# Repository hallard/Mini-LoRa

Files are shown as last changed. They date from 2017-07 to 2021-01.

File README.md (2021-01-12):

Mini Lora Node, Arduino Mini LoraWAN sensor
===========================================

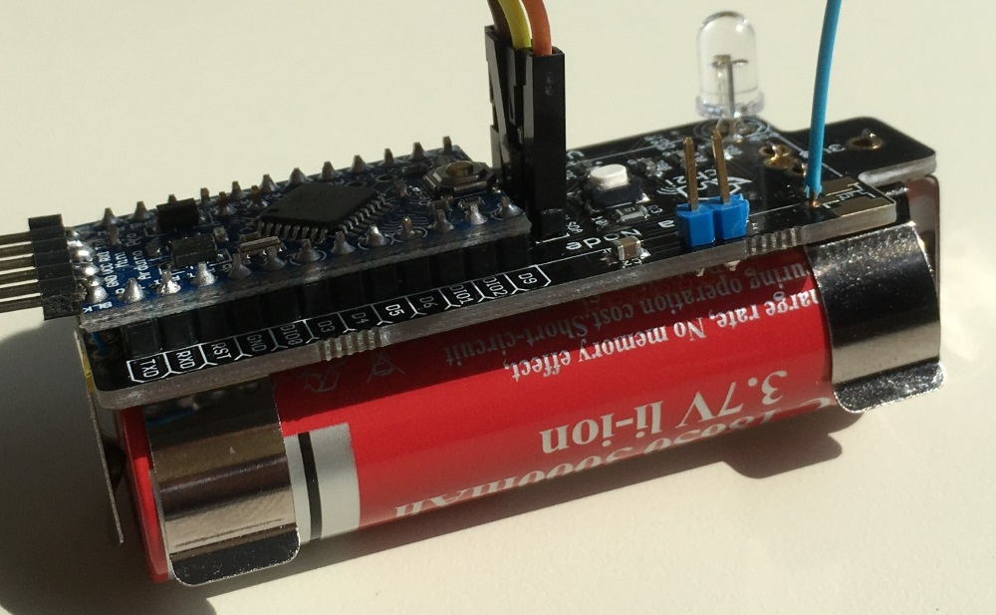
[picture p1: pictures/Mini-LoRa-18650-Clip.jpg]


At the begining this PCB has been created to help wiring between Arduino Mini and RFM95 Lora module and to be able to put the whole thing powered by various Batteries type (AA, 18650, A, ...).

Then I decided to add some funky stuff like:

**new in V1.2**

- Footprint for Ultra Low Power controller TPL5110
- R9 1206 or PTH Footprint to easily change resistor and thus delay between wake
- renamed silk pin to function instead of arduino name
- Optional Tactile Switch to wake from TPL5110

**all version**

- Easy to build and solder, 0805 or PTH components
- I2C connector (or grove) to be able to add internal/external sensors such as BME280, SI7021 or HTU21D
- Footprint for Lora RFM95
- Footprint for a Microchip 24AA02E64T EUID 
- RBG Led
- Optional Tactile Switch
- Various Battery Connector and type AA/A/18650/CR123
- Two A4/A5 pins position so you can use different Mini Clone (see BOM)

**On version 1.1, I2C A4/A5 (the ones bottom right) are not connected**, thanks to tkerby who detected this point on [issue #1](https://github.com/hallard/Mini-LoRa/issues/1).
This is now fixed on version 1.1a. Pcbs.io PCB have been updated.

Detailed Description
====================

No specific documentation for now, it's just a kind of wiring helper as follow

```
 Arduino Mini   RFM9x Module
 A0          <----> RST
 MISO  (D12) <----> MISO
 MOSI  (D11) <----> MOSI
 SCK   (D13) <----> CLK
 SS    (D10) <----> SEL (Chip Select)
 D2          <----> DIO0
 D7          <----> DIO1
 D8          <----> DIO2

 Arduino Mini    Shield PCB
 D3          <----> Push Button (Has Pull Down)
 D9          <----> Led Red
 D6          <----> Led Green
 D5          <----> Led Blue
 A1          <----> DONE of TPL5110 (to indicate we done)
 A2          <----> DRVN of TPL5110 (pulse out to wake CPU)
 SDA (A4)    <----> I2C SCL Connector
 SCL (A5)    <----> I2C SDA Connector
```

R9 determine Wake Time interval from TPL5110 as follow 
  - 170K 2 hours
  - 120K ~1 hour
  - 100K ~35 min
  - 47K ~6 min

please read TPL5110 [datasheet](http://www.ti.com/lit/ds/symlink/tpl5110.pdf) for more information or Adafruit TPL5110 Learning [page](https://learn.adafruit.com/adafruit-tpl5110-power-timer-breakout/)

Installation
============

If you're using Battery clip connector, please isolate the A4/A5 and FTDI (V1.0 only) pads from clip because it will do shorts and prevent I2C to work.

I'm Using the [LMIC stack](https://github.com/matthijskooijman/arduino-lmic) as his with custom sketch, this one is under NDA for Ultra Low Power, So I can't provide it but you can use the one in example of LMIC.

You may need to disable debug of LMIC stack if missing.

I'm also changing the Bootloader to use optiboot and win 1.5K of flash code and setup the Brown Out Detect to 1.8V to be able to works under 2.7V. Please see this [Pro-Mini-ICSP-FTDI](https://github.com/hallard/Pro-Mini-ICSP-FTDI) repo if you need to flash your Arduino Pro Mini with this bootloader. You'll see in [bootloader](https://github.com/hallard/Pro-Mini-ICSP-FTDI/tree/master/bootloaders) folder, I've compiled some for various Speed and for 8MHz and 16MHz Crystal (I use the 250KBPS one, it's fast and reliable).

I've also created custom board definition for Arduino IDE so if using my bootloader, you'll have the board clock and serial speed selection in Arduino IDE, it located [here](https://github.com/ch2i/ch2i-arduino-boards)

Schematic
=========

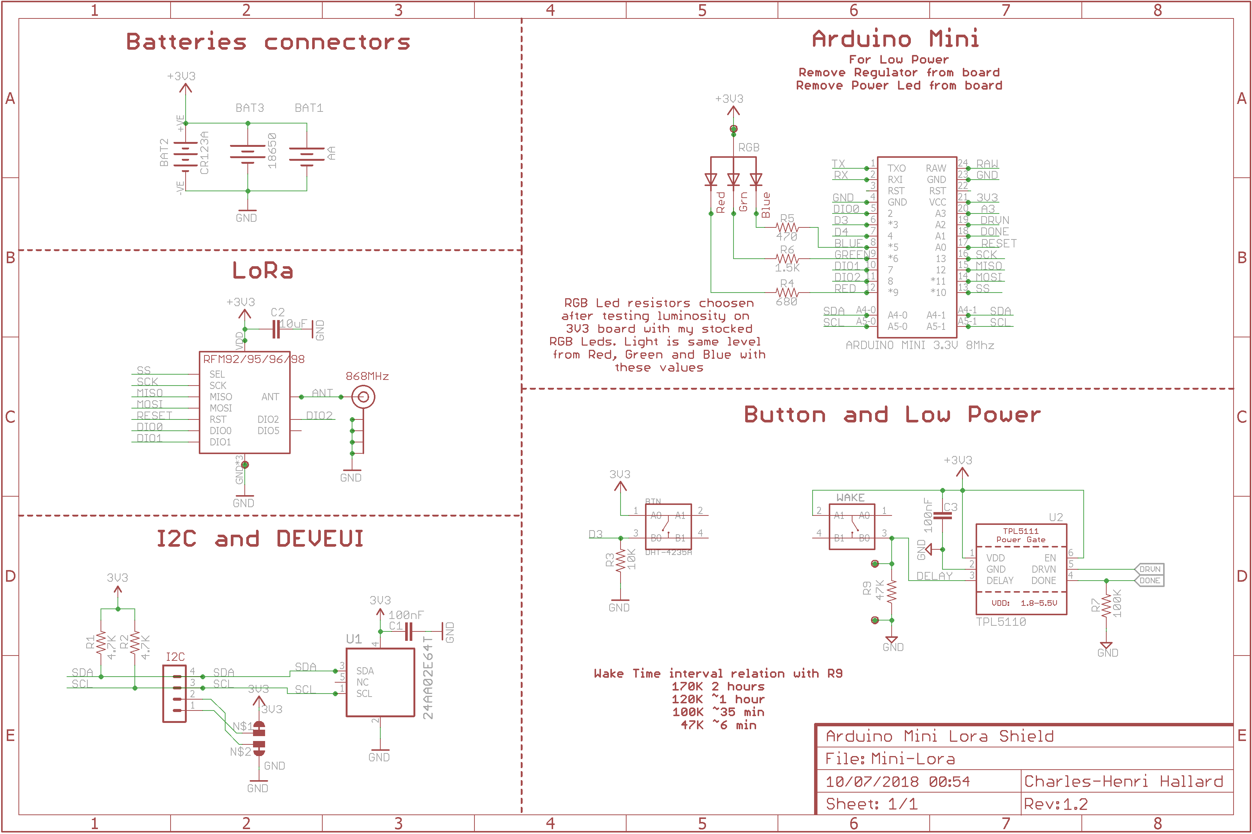
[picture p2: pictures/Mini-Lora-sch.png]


Boards 
======

**Top & bottom side V1.2**

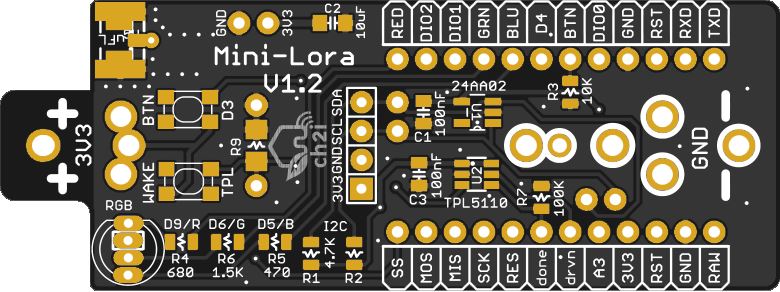
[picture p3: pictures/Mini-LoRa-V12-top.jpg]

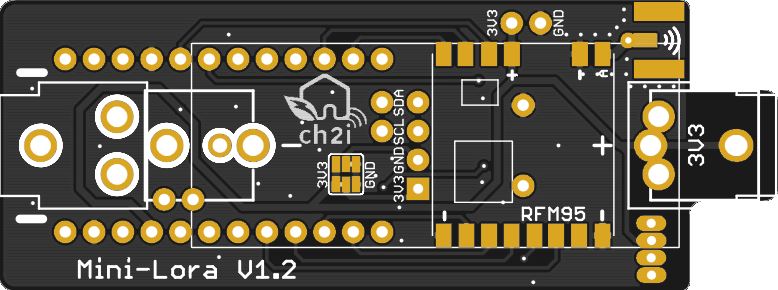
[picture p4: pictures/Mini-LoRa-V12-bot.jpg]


**Top & bottom side Grove V1.1**

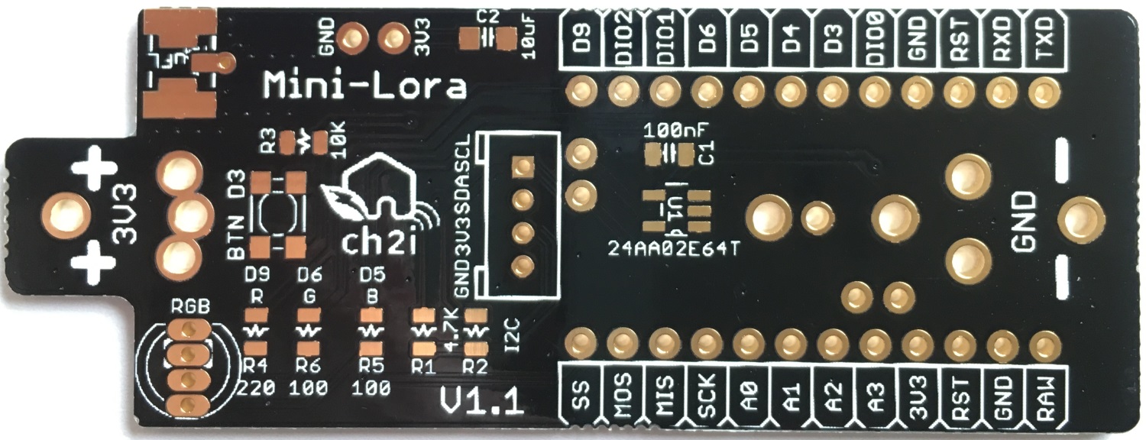
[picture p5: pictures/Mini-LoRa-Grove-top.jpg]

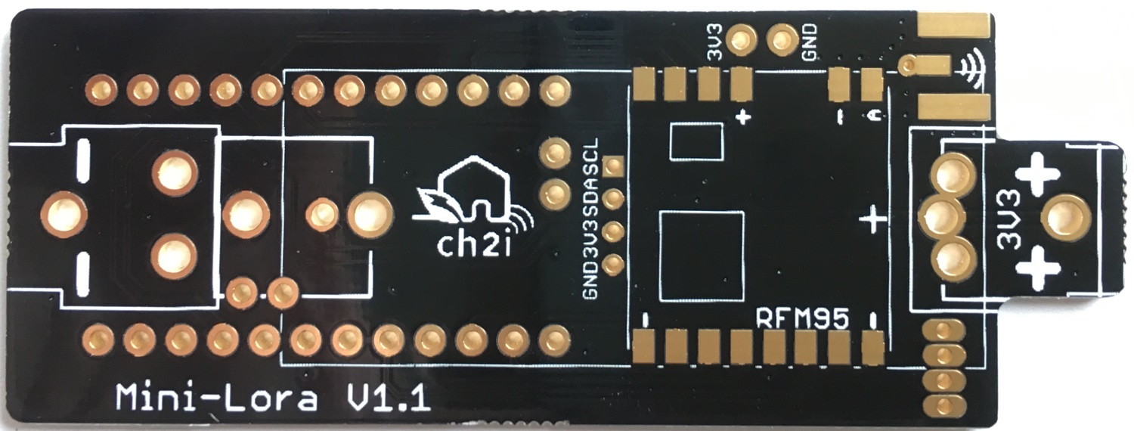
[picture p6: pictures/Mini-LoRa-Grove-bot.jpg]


~~You can order PCBs of this board at [PCBs.io][3]~~

- ~~[V1.2](https://www.PCBs.io/share/r1a3J) Classic I2C connector~~
- ~~[V1.1a](https://www.PCBs.io/share/8AGb2) Classic I2C connector~~
- ~~[V1.1a](https://www.PCBs.io/share/zjKdY) Grove I2C connector~~
- ~~[V1.0](https://www.PCBs.io/share/r3LdE)~~

 ~~PCBs.io give me some reward when you order my designed boards from their site. This is pretty good, because I can use these rewards to create and design new boards and order boards for a discounted price, so if you don't care about PCB manufacturer please use PCBs.io.~~

Looks like PCBs.io is gone, I do not have any rewards from PCBs.io since August 2020 and my free order placed after are still not received, so my guess they are not on business anymore.

So you can order the board on [oshpark](https://oshpark.com). 

- [V1.2](https://oshpark.com/shared_projects/xBynTfXX) Classic I2C connector
- [V1.1a](https://oshpark.com/shared_projects/TSE77q5q) Groove I2C connector

It's a pitty after several discuss with OSHPark that I can't have any rewards for each people ordering my boards, this would allow me to order free PCB for shared projects and create new ones. For information my shared boards generated a total of **$285 162.00** orders at PCBs.io in 4 years, not bad at all :-)

Hoping one day OSHparks will thanks me giving them this market. 

Assembled boards with sensors
=============================

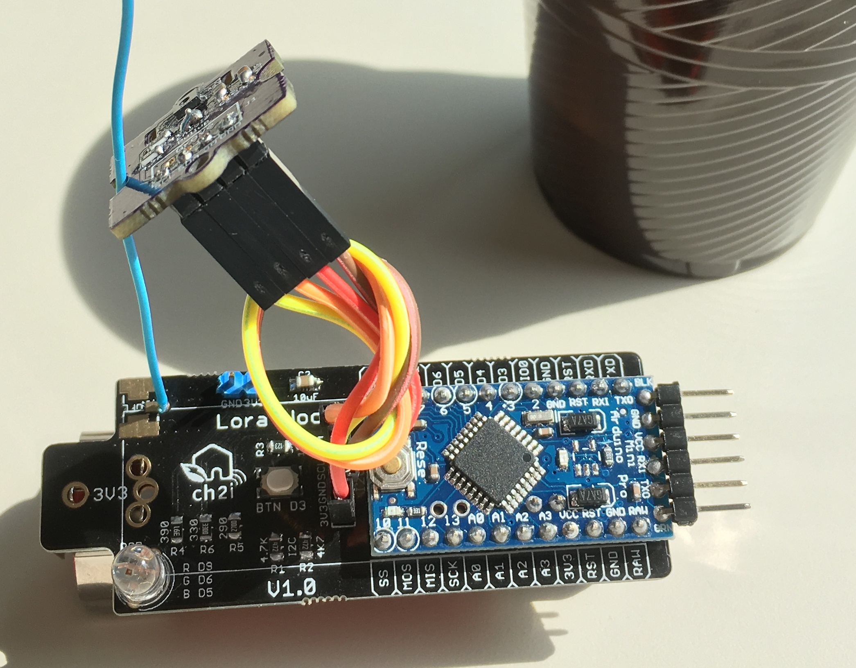
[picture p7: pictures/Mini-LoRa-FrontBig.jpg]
Fully assembled with sensors


Sensors values en Cayenne
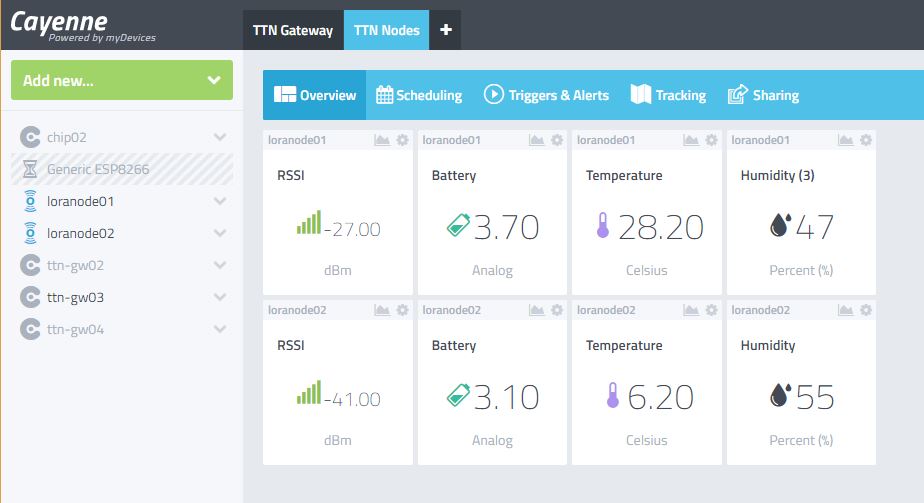
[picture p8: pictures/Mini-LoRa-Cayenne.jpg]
Monitoring with external sensors


Bill Of Material
================

Nothing fancy, all components are 0805 and/or PTH and can be ordered almost anywhere (digikey, mouser, radiospare, ...). 
use only what you need dependings on what you want to do. 

Octopart [BOM file](https://octopart.com/bom-tool/MsqCYjTr)

Example of option parts, and other source
- Arduino Pro Mini (just take care your board has A4/A5 at the correct place, some clone are not)
    - [Geekcreit](https://www.banggood.com/Pro-Mini-ATMEGA328P-5V16M-Improved-Version-Module-For-Arduino-p-985618.html) 5V 16MHz (power it with 3.3V and/or remove regulator)
    - [ebay](http://www.ebay.com/itm/201562503063) 3V3 8MHz
- [RFM95](https://www.digikey.com/product-detail/en/rf-solutions/RFM95W-868S2/RFM95W-868S2-ND/5051755) (check Frequency)
- Common Anode RGB Led, search `diffused 5MM RGB LED common anode` on ebay
- Battery Connector format
    - Holder [AA](https://www.digikey.com/product-detail/en/mpd-memory-protection-devices/BCAAPC/BCAAPC-ND/232723)
    - Clip [AA](https://www.digikey.com/product-detail/en/mpd-memory-protection-devices/BK-92/BK-92-ND/2079904)
    - Clip [A/18650](https://www.digikey.com/product-detail/en/keystone-electronics/54/36-54-ND/2254090) 
    - PTH [CR123](https://www.digikey.com/product-detail/en/mpd-memory-protection-devices/BH123A/BH123A-ND/2817712)
- Batteries
    - 3.0V Lithium [CR123](https://www.digikey.com/product-detail/en/panasonic-bsg/CR-123PE-BN/P703-ND/7064720)
    - 3.6V Lithium Thionyle Chloride [2600mAh](http://fr.rs-online.com/web/p/piles-aa/2019438/)
    - 3.6V Lithium Thionyle Chloride [3600mAh](http://fr.rs-online.com/web/p/piles-aa/778-1087/)

License
=======

   

This work is licensed under a [Creative Commons Attribution-NonCommercial 4.0 International License](http://creativecommons.org/licenses/by-nc/4.0/)    
If you want to do commercial stuff with this project, please contact [CH2i company](https://www.ch2i.eu/en#support) so we can organize an simple agreement.

Misc
====

See TTN dedicated [post](https://www.thethingsnetwork.org/forum/t/8059) and news and other projects on my [blog][1] 
 
[1]: https://hallard.me
[3]: https://www.PCBs.io

[20]: http://www.seeedstudio.com/depot/index.php?main_page=opl_info&opl_id=4
[21]: http://www.ebay.com/itm/170578495165
[22]: http://www.ebay.com/itm/351690376555
[23]: http://www.ebay.com/itm/351738196013
[24]: http://www.ebay.com/itm/371534934746
[25]: https://www.adafruit.com/products/1979
[26]: https://www.sparkfun.com/products/11114

[27]: http://www.ebay.com/itm/121929386506?var=420920026758
[28]: http://www.ebay.com/itm/371348168950
[29]: http://www.ebay.com/itm/351588181858

[40]: http://www.ebay.com/itm/262500056078
[41]: http://www.aliexpress.com/item/Free-Shipping-Good-Quality-ABS-Material-Transparent-Cover-IP66-Waterproof-Electrical-Switch-Box-125-125-75mm/32522255056.html
[42]: http://www.aliexpress.com/item/Temperature-and-humidity-Protective-sleeve-Accessories-PCB-for-SHT20-SHT21-SHT25/32695663191.html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
[43]: http://www.ebay.com/itm/401000227934
[44]: http://www.ebay.com/itm/182181715511?var=483966356069
[46]: http://www.ebay.com/itm/391462862706
[47]: http://www.ebay.com/itm/232153789354?var=531358445664
[48]: http://www.ebay.com/itm/301856945402

[50]: https://octopart.com/bom-tool/MsqCYjTr

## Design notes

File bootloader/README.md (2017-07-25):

Bootloaders
===========

bootloaders folder has moved to my [Pro-Mini-ICSP-FTDI](https://github.com/hallard/Pro-Mini-ICSP-FTDI) shield.

Pro-Mini-ICSP-FTDI 

You can find them into [bootloaders](https://github.com/hallard/Pro-Mini-ICSP-FTDI/tree/master/bootloaders) folder.

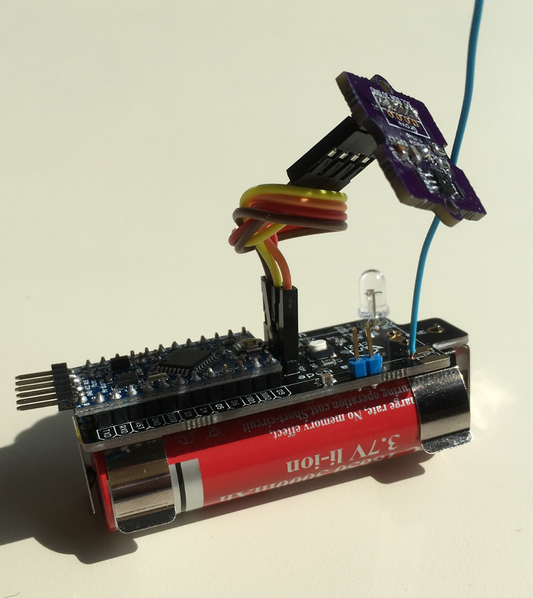
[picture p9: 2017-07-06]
pictures/Mini-LoRa-Back.jpg

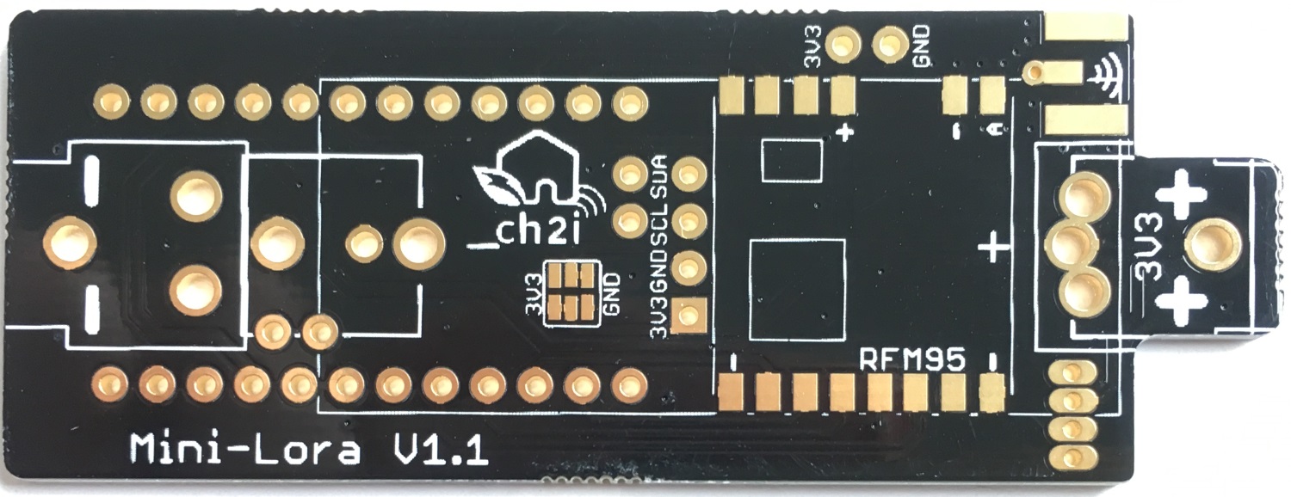
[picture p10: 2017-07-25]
pictures/Mini-LoRa-bot.jpg

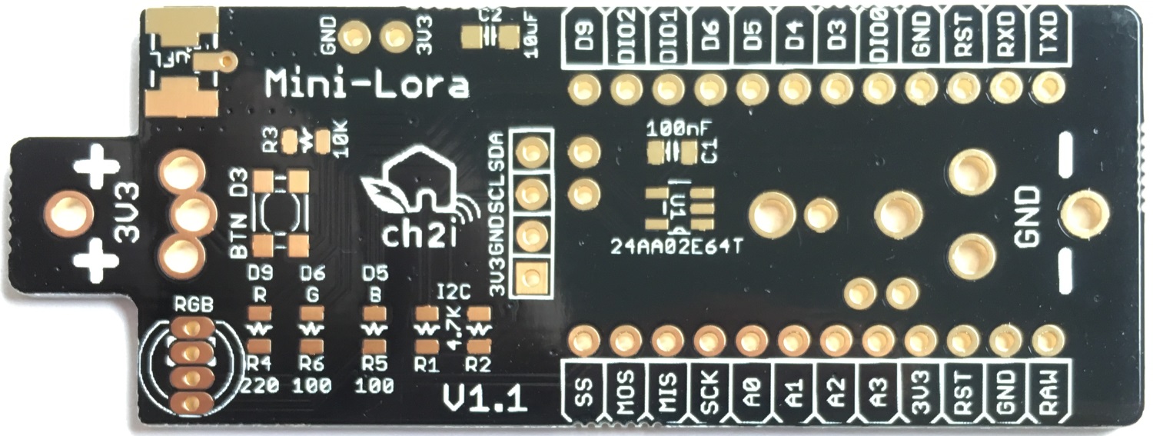
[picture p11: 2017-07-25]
pictures/Mini-LoRa-top.jpg

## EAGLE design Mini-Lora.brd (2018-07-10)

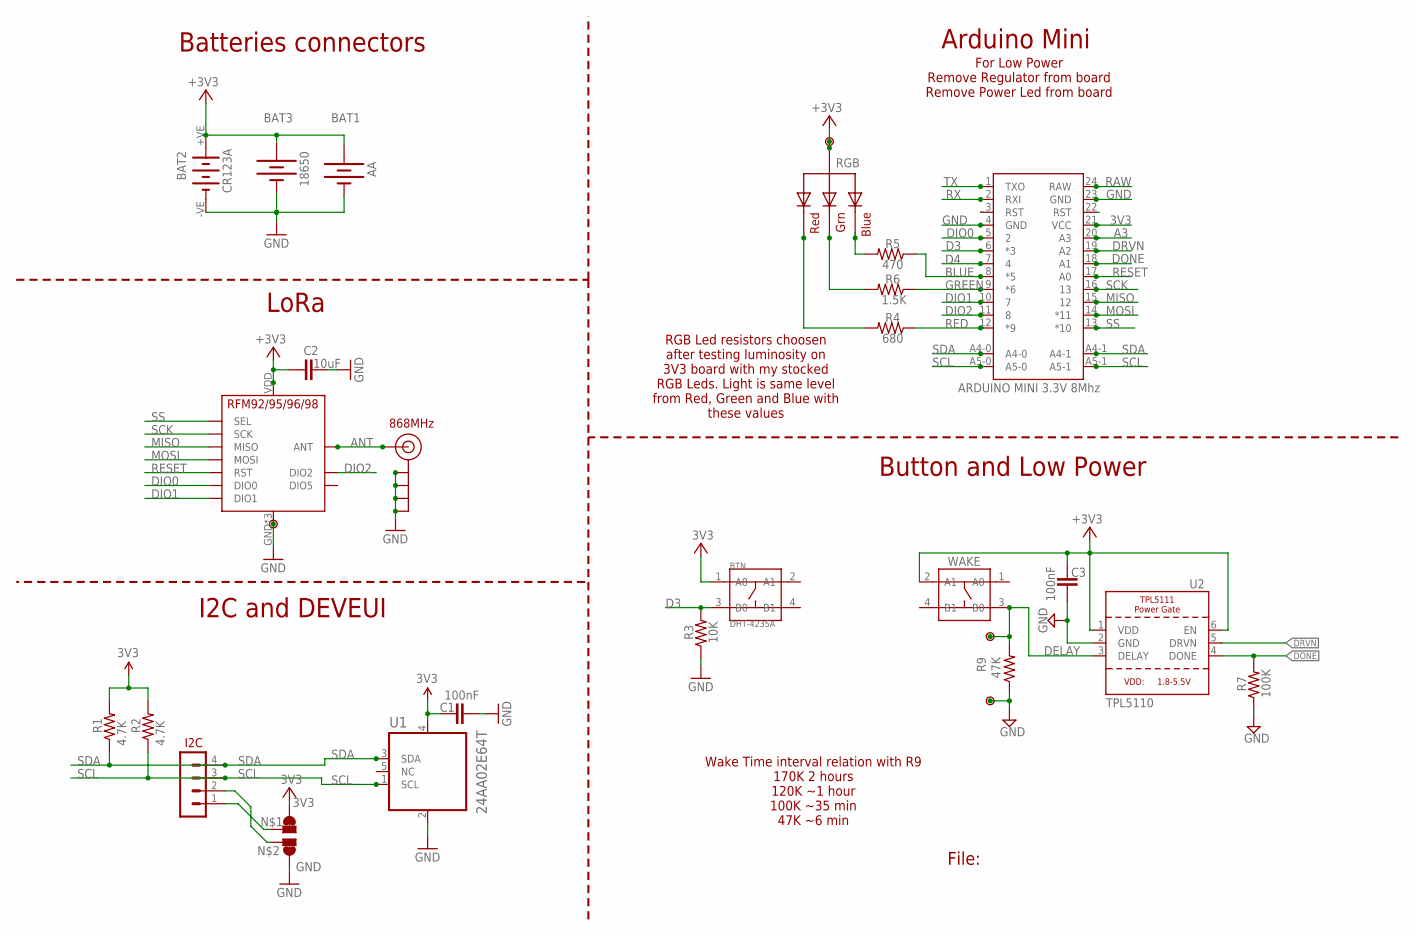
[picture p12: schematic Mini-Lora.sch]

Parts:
BAT1: AA; BATTERY-AA
BAT2: CR123A; KEYSTONE-2/3A
BAT3: 18650; BATTERY_18650-HOLDER
BTN: DHT-4235A; SW4-SMD-4.2X3.2X2.5MM
C1, C3: 100nF; 0805-CAP
C2: 10uF; 0805-CAP-LARGEPADS
I2C: CON_HEADER_1X04'NO_LOCK'; 1X04_NO_LOCK
J$2: ANTENNATINY; SMA_UFL_PAD_TINY
P1: GND; PAD
P2, P3, P4: PADNORMAL; PAD
R1, R2: 4.7K; 0805-RES
R3: 10K; 0805-RES
R4: 680; 0805-RES
R5: 470; 0805-RES
R6: 1.5K; 0805-RES
R7: 100K; 0805-RES
R9: 47K; 1206-RES
RGB: RGBLED; LED5MMRGB_ST
U1: 24AA02E64T; SOT95P270X145-5N
U2: TPL5110; SOT23-6
U$1: PAD-JUMPER-SWAPSWAP; PAD-JUMPER-SWAP
U$5: RFM95
U$6: ARDUINO MINI 3.3V 8Mhz; ARDUINO_PRO_MINI
WAKE: WAKE; SW4-SMD-4.2X3.2X2.5MM

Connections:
3V3: BAT1.PWR@1 (+), BAT2.+VE (+), BAT3.PWR@1 (+), BTN.1 (A0), C1.1, C2.2, C3.1, P4.1, R1.2, R2.2, RGB.2 (VCC), U1.4 (VCC), U2.1 (VDD), U2.6 (EN), U$1.4, U$1.44 (4), U$5.VDD (VCC), U$6.21 (VCC), WAKE.2 (A1)
A3: U$6.20 (A3)
ANT: J$2.ANT1 (SIGNAL), J$2.ANT2 (SIGNAL), J$2.ANT3 (SIGNAL), U$5.ANT
BLUE: R5.1, U$6.8 (*5)
D3: BTN.3 (B0), R3.2, U$6.6 (*3)
D4: U$6.7 (4)
DELAY: P2.1, R9.2, U2.3 (DELAY), WAKE.3 (B0)
DIO0: U$5.DIO0, U$6.5 (2)
DIO1: U$5.DIO1, U$6.10 (7)
DIO2: U$5.DIO2, U$6.11 (8)
DONE: R7.2, U2.4 (DONE), U$6.18 (A1)
DRVN: U2.5 (DRVN), U$6.19 (A2)
GND: BAT1.GND@1 (-), BAT2.-VE (-), BAT3.GND@1 (-), C1.2, C2.1, C3.2, J$2.GND1 (GND), J$2.GND2 (GND), J$2.GND3 (GND), J$2.GND4 (GND), P1.1, P3.1, R3.1, R7.1, R9.1, U1.2 (VSS), U2.2 (GND), U$1.1, U$1.11 (1), U$5.GND, U$5.GND1 (GND), U$5.GND2 (GND), U$6.4 (GND), U$6.23 (GND)
GREEN: R6.1, U$6.9 (*6)
LB: R5.2, RGB.4 (BLUE)
LG: R6.2, RGB.3 (GREEN)
LR: R4.2, RGB.1 (RED)
MISO: U$5.MISO, U$6.15 (12)
MOSI: U$5.MOSI, U$6.14 (*11)
unnamed: I2C.1, U$1.3
unnamed: I2C.2, U$1.2
RAW: U$6.24 (RAW)
RED: R4.1, U$6.12 (*9)
RESET: U$5.RST, U$6.17 (A0)
RST: U$6.22 (RST)
RX: U$6.2 (RXI)
SCK: U$5.SCK, U$6.16 (13)
SCL: I2C.3, R2.1, U1.1 (SCL), U$6.A5-0, U$6.A5-1
SDA: I2C.4, R1.1, U1.3 (SDA), U$6.A4-0, U$6.A4-1
SS: U$5.NSS (SEL), U$6.13 (*10)
TX: U$6.1 (TXO)

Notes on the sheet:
File:
868MHz
Wake Time interval relation with R9 170K 2 hours 120K ~1 hour 100K ~35 min 47K ~6 min
Button and Low Power
Arduino Mini
I2C and DEVEUI
LoRa
Batteries connectors
For Low Power Remove Regulator from board Remove Power Led from board
RGB Led resistors choosen after testing luminosity on 3V3 board with my stocked RGB Leds. Light is same level from Red, Green and Blue with these values

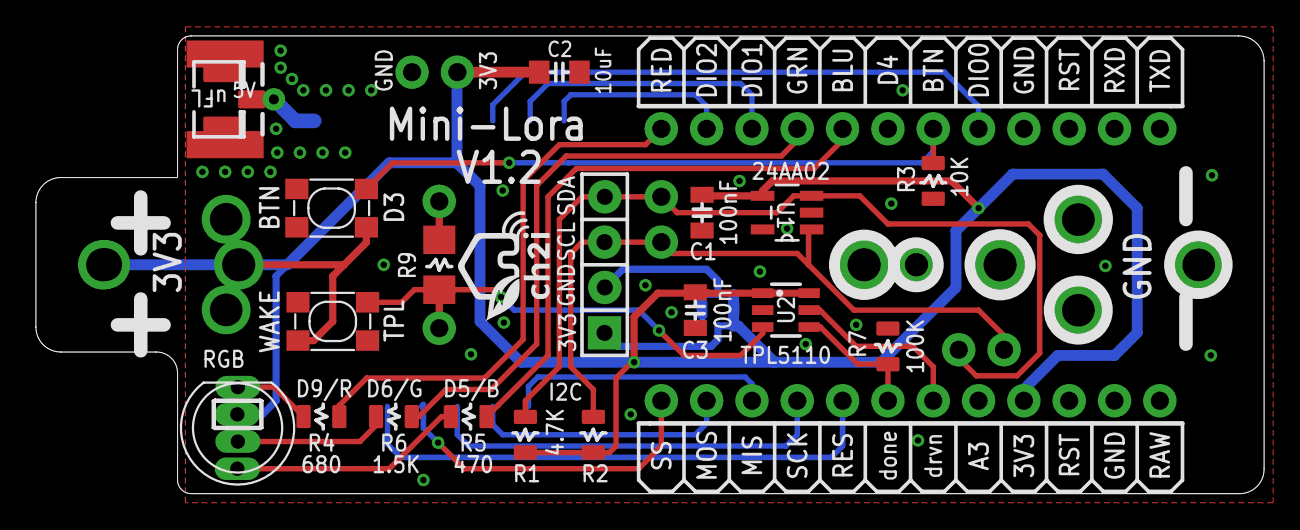
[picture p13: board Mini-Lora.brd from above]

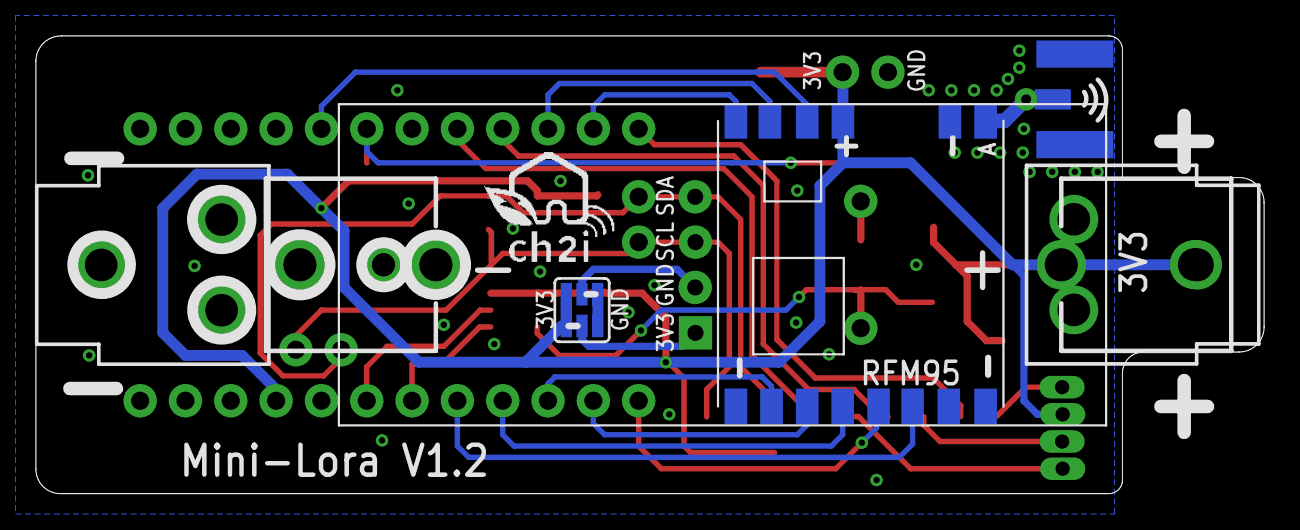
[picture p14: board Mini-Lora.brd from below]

Board: 2 copper layers, 68.8 x 25.7 mm, 30 parts (6 on the bottom side), 25 nets.

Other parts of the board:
U$2: LOGO_C2I_015
U$4: LOGO_CH2I_75MM

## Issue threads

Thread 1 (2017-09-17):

Alternate A4/A5 connection

tkerby, 2017-09-17:
Alternate location of A4 / A5 I2C on long side of Arduino are not connected to I2C

tkerby, 2017-09-17:
Looks like they were connected in version 1. Is this part of the change to prevent contact with battery clips or an omission?

hallard, 2017-09-18:
Absolutely, this is an error!
thanks for mentioning it, it's now fixed in V1.1a

Closed 2017-09-18.

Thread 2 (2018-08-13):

TPL5110 - Wake pin

ricaun, 2018-08-13:
I realy like the ideia to use TPL5110 to manager a wakeup timer.

But I don't understand why you put the DRVN of TPL5110 on A2 pin...

Maybe change to pin D3 how haves external interrupt, this way is possible to put the arduino on SLEEP_FOREVER and TPL5110 will wakeup. And put the button to D4.

ricaun, 2018-08-15:
Nice!!
I didn't know that pin change interrupts can wake up the arduino,
That's awesome, I need to try some codes.

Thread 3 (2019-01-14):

TPL5110

dijus, 2019-01-14:
Is the TPL5110 necessary for V1.2 board to work, is there any workarounds? Because i already bought the pcb's and i did not think that my country doesnt have the TPL5110.

hallard, 2019-03-11:
I think it's not necessary and then you can use ATMEGA internal watchdog t wake up device

Closed 2019-03-11.

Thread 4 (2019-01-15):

RFM95 could be destroyed by full 18650.

mvdswaluw, 2019-01-15:
Hello,

a freshly charged 18650 could destroy your RFM95 in this design. The charged battery will give 4.2V, while the absolute max voltage of the RFM95 is 3.9V. This could be solved by adding a power regulator on the PCB triggered by the TPL5510 like in on the "trigboard", or low-budget by adding a diode to get some mV drop for the RFM95 VCC.

hallard, 2019-03-11:
Absolutely,
That's why the 18650 charged battery is not in the BOM file, only 3.6V battery.

Closed 2019-03-11.

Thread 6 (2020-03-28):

The proposed RGB LED in the Octopart BOM is "common cathode"

crox-net, 2020-03-28:
As indicated in the README, the circuit is designed for a "common anode" RGB LED, however the LED in the Octopart BOM is "common cathode".

I've ordered this one instead:

LED RGB DIFFUSED T-1 3/4 T/H
Manufacturer: Kingbright
Manufacturer Part Number: WP154A4SEJ3VBDZGW/CA

crox-net, 2020-04-04:
I've received the LED, and while it works (common anode), green and blue are inverted.

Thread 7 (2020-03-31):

Mini-Lora, LMIC and TTN

jocelynduc, 2020-03-31:
Hi,

Does somebody has a working example with this node, using LMIC library and TTN?

Can't get it working (EV_JOINING, nothing more). Is maybe my pin map incorrect?

```
const lmic_pinmap lmic_pins = {
    .nss = 10,
    .rxtx = LMIC_UNUSED_PIN,
    .rst = A0,
    .dio = {2, 7, 8},
};
```

Thanks

crox-net, 2020-04-04:
Hi,

I have a "hello world" working with TTN. Working on a better example that I can publish (including making good use of the TPL5110), but maybe you beat me to it :-)

This works for me:

// Pin mapping
const lmic_pinmap lmic_pins = {
    .nss = 10,
    .rxtx = LMIC_UNUSED_PIN,
    .rst = 15,
    .dio = {2, 7, 8},
};

jocelynduc, 2020-04-05:
Hi,

Good idea! A ready-to-use implementation for this node (and TTN) is missing, especially for beginners like me ;) I now there are tons of LMIC examples, but not able to get it working.

I think it's more a problem of device configuration (TTN keys) right now, as I am able to send a JOIN request with OTAA or a message with ABP (visible in TTN gateway console, but not in Application).

Do you work with OTAA or ABP? Can you share a bit more?

A good use of the TPL5110, I am not sure if I can really help with the correct way to do it. I saw some tutorials where the Arduino was directly feed from the DRVN output of the TPL, in order to power it off completely in case of DONE. In our case, the DONE/DRVN are mapped on pins A1 and A2 (and not RAW), so my idea was to deal with it with some LowPower library and interrupts

I share my current work, maybe it can help... or correct me if I am totally wrong ;)
https://bitbucket.org/jocelynduc/lora-mini-node/src/master/lora-mini-node.ino

With a #define switch, I can choose:
- to sleep up to 8 seconds thank to the LowPower lib,
- or until the D3 button is pressed
- or until the WAKE button is pressed (or after the period of time defined by the R9 resistor)

crox-net, 2020-04-05:
Thanks for sharing!

I've put what I have here: [crox-net/mini-lora-examples](https://github.com/crox-net/mini-lora-examples)

My understanding is indeed that in this design the TPL5110 will not cut power to the MCU, but just "wake" it using a pin change interrupt on A2 (aka pin 16, PCINT10).

crox-net, 2020-04-28:
Getting there :-) I've just published a new sketch (ttn-otaa-bme280-tpl5110) at the link above.

Rock-N-RollaMann, 2020-05-01:
Hey, one reason your device may not be connecting is because of a bug in the new updated "LMIC Library". It was happening with me with my device although I am using a feather m0 from adafruit. I just downgraded to a lower version of the library. I was pulling my hair for like 4 days trying to figure out why my device wasn't working anymore. Hope this helps!

Closed 2020-05-01.

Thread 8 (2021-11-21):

Code sample to wake using A2

eboston, 2021-11-21:
Is there some sample code available on how to wake the Arduino using the A2 pin?  I have been able to play around with it and see the level on A2 changing, I can get it to trigger an interrupt.

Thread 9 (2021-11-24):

TPL5110 Not Working

eboston, 2021-11-24:
I have been fighting with getting the TPL5110 circuit to work with no luck.  It never turns on.  When I first apply power to the board, I see a small spike on the DRVN line, but then it goes to zero.  Pressing the wake button does not do anything.  I have check everything several times and can't find any problems.  I swapped out the TPL5110 with another one on a working board (Not a Mini-LoRa).  The one that was on the Mini-LoRa works in the other board and the one from the other board now doesn't work on the Mini-LoRa.  I have checked for solder bridges and shorts and cannot find anything wrong.  The circuit is so simple, I can't understand why it is not working.  It is pretty much the same circuit as my other board.  Only difference is the Mini-LoRa has a pull-down resistor on DONE.  Any suggestions on this would be welcomed.

eboston, 2021-11-25:
Was able to get things working by removing R7.

Closed 2021-11-25.

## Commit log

2017-07-25 Added new PCBs.io links
2017-09-18 Bump to V1.1a
    [Mini-Lora-Grove.brd, Mini-Lora-Grove.sch, Mini-Lora.brd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]
2017-09-18 Updated BOM + V1.1a
2018-07-10 Bump to V1.2
    [Mini-Lora.brd, Mini-Lora.sch]
2019-07-07 Added link toi boards definition

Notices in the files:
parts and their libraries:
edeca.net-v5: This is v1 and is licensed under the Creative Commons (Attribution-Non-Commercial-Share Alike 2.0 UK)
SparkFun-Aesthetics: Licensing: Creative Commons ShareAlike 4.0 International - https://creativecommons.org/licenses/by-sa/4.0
